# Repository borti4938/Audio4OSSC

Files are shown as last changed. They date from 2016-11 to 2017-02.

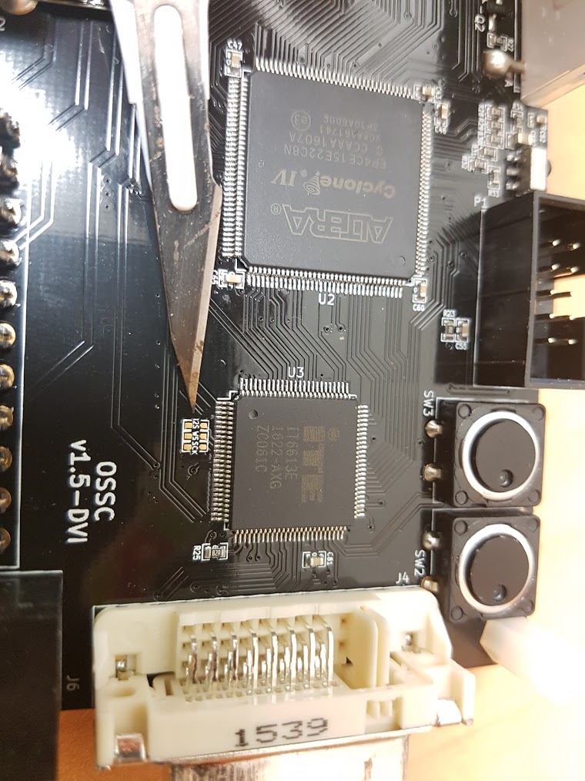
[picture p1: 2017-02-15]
installation/v1.5-A3a/installation_ae_02a.jpg

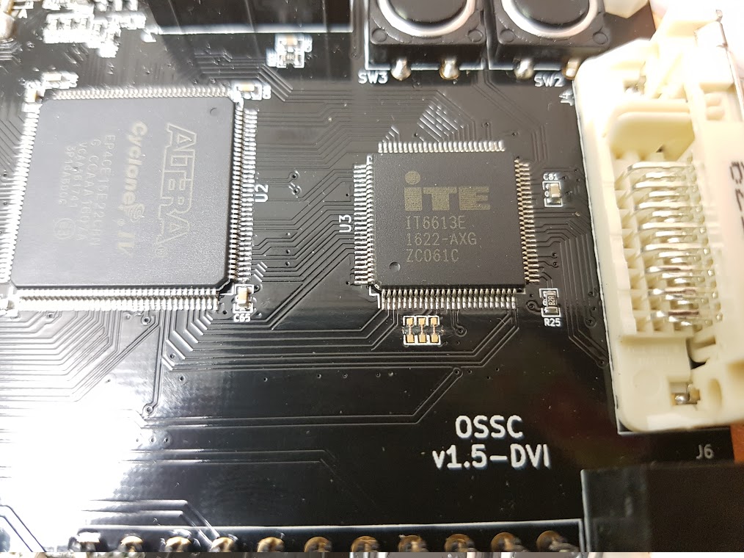
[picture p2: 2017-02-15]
installation/v1.5-A3a/installation_ae_02b.jpg

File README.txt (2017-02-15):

The OSSC does not output audio over HDMI or DVI-D, respectively. This add on captures the analoge audio you feed over the SCART or audio 3.5mm stereo jack. The audio signal is digitalize and put into the IT6613E over the I2S audio interface.
This repository provides the hardware design for the modification. The installation requires installation effort which depends on the OSSC version number you have.

Firmware
========
The IT6613E has to be programmed appropriately to insert audio to the digital video output. In the 'original' firmware audio is not taken into account. Therefore the firmware of the OSSC has to be updated.
Up to the OSSC firmware version v0.73 you can grab the current firmware in this repository. With v0.74 the source code part needed for the audio modification was integrated to the official GitHub branch by marqs85. The builds can be grabbed from the official source: https://www.niksula.hut.fi/~mhiienka/ossc/fw/. Additionally, I provide a mirror here.

PCB Production
==============
Choose the service you would ever like. I have uploaded the design to OSHPark, too.
VERY IMPORTANT: The substrate thickness has to be as thin as possible.
The PCB for v1.3 is design to sit between lifted pins of the IT6613 (the HDMI transmitter) and OSSC-PCB (just look at the installation pictures to get an idea ;)). With v1.5 the OSSC comes with jumpers which are connected to the appropriate pins of the IT6613E. The add-on sits on top of the jumpers (don't forget to open them). 
I have produced the PCBs with OSHPark and have chosen 0.8mm thickness. The PCB must not be thicker.
Link to PCB at OSHPark:
- https://oshpark.com/shared_projects/rmFBAKyo (for v1.3)
- https://oshpark.com/shared_projects/vKUEgBSy (for v1.5)
- https://oshpark.com/shared_projects/WeKdeoGP (for v1.5 with wired connection to the SCART)

Part list of the DIY-Audio PCB
==============================
running number ------ footprint(s) --------- device/part --------- package ----- mouser ordering key
     01         |  U1                 |  PCM1808               |  TSSOP14     |  595-PCM1808PWR
     02         |  U2                 |  74LVC1G34             |  SOT23-5     |  595-SN74LVC1G34DCKR
     03         |  U3                 |  MK2705SLF             |  SOIC8       |  972-MK2705SLF
     04         |  FB1, FB2           |  Ferrit Beat           |  SMD0603     |  81-BLM18PG471SN1D
     05         |  C1                 |  tantal-cap. 47uF/16V  |  SMD case C  |  74-293D476X9016C2TE3
     06         |  R11, R12           |  res. >2.2 kOhm        |  SMD0603     |  71-CRCW06034K99FKEAH (e.g. 4.99k)
     07         |  C11, C13, C15      |  tantal-cap. 10uF/6.3V |  SMD case A  |  74-TR3A106M6R3C1500
     08         |  C12, C14, C16, C21 | cap. 0.1uF/50V         |  SMD0603     |  77-VJ0603V104MXACBC
     09         |  C17, C18, C31      | tantal-cap. 1uF/16V    |  SMD case A  |  74-293D105X9016A2TE3
     10         |  R19, R20           | res. ***               |  SMD0603     |  see description below
     11         |  C19, C20           | cap. ***               |  SMD0603     |  see description below
     12         |  R31                | res. 33 Ohm            |  SMD0603     |  71-CRCW060333R0FKEAH
     13         |  C32, C33           | cap. 0.01uF/50V        |  SMD0603     |  77-VJ0603Y103KXACBC

RC-filtering of the Audio
=========================
The RC filters (R19,C19) and (R20,C20) mainly bandlimits the noise. The filter also avoids aliasing effects if the bandwith of the audio signal increases.
The PCM1808 samples the audio signal with 96kHz. This means that the cut-off frequency of the filters have to be 96kHz or below. The firmware will also allows you to further downsample the datastream to 48kHz. If you want to use that I recommend you to set the filter to 48kHz or below to avoid aliasing.
The cut-off frequency f_c of a simple RC low pass filter is determined by f_c = 1/(2*pi*R*C).
here is my choice which gives a cut-off frequency of 47.938kHz.
     10         |  R19, R20  |  res. 3.32 kOhm   |  SMD0603  |  71-CRCW0603-3.32K-E3  
     11         |  C19, C20  |  cap. 1000pF/50V  |  SMD0603  |  77-VJ0603Y102KXACBC

PCB-Installation
================  
See folder installation ;)
  
For providing pictures, thank you to  
- Kharmeleon (user from Circuit-Board.de)  
- Kabloui (user/customer from VGP)

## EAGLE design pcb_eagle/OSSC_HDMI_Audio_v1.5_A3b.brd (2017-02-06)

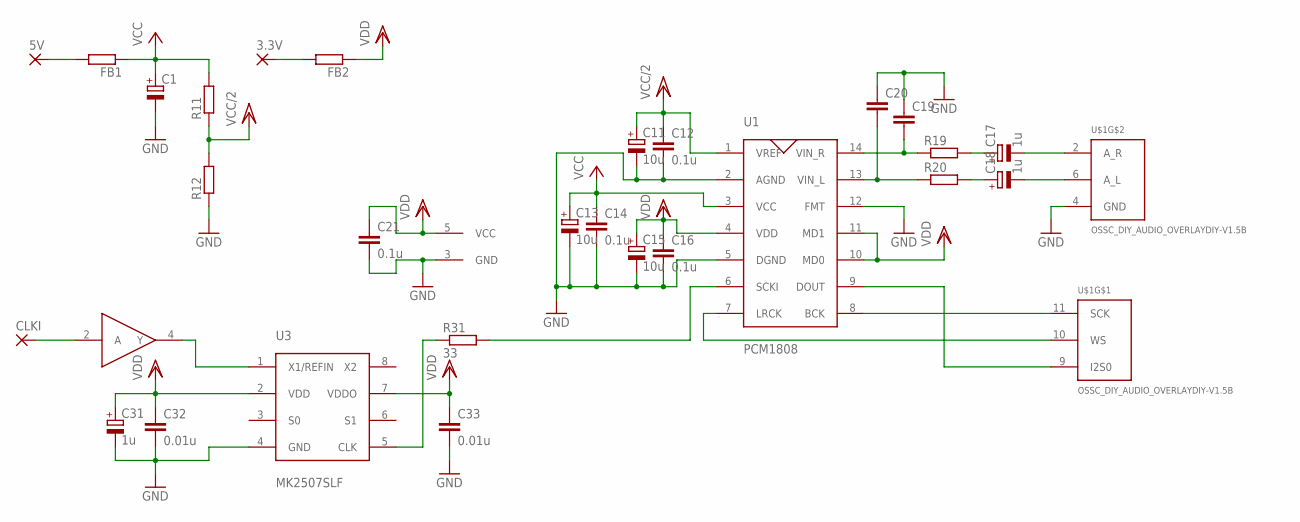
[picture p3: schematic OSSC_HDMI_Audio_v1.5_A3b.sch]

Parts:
3.3V, 5V: SMD2; SMD1,27-2,54
C1: CPOL-EUSMCC; SMC_C
C11, C13, C15: 10u; SMC_A
C12, C14, C16, C21: 0.1u; C0603
C17, C18, C31: 1u; SMC_A
C19, C20: C-EUC0603; C0603
C32, C33: 0.01u; C0603
CLKI: SMD2; SMD1,27-2,54
FB1, FB2: R-EU_R0603; R0603
R11, R12, R19, R20: R-EU_R0603; R0603
R31: 33; R0603
U1: PCM1808
U2: 74LVC1G34; 74LVC1G34DCK
U3: MK2507SLF; SOIC8
U$1: OSSC_DIY_AUDIO_OVERLAYDIY-V1.5B; OSSC_OVERLAY_V1.5B

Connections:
GND: C1.-, C11.-, C12.2, C13.-, C14.2, C15.-, C16.2, C19.1, C20.1, C21.2, C31.-, C32.2, C33.2, R12.1, U1.2 (AGND), U1.5 (DGND), U1.12 (FMT), U2.3 (GND), U3.4 (GND), U$1.4 (GND)
unnamed: C18.-, U$1.6 (A_L)
unnamed: C17.-, U$1.2 (A_R)
unnamed: C17.+, R19.2
unnamed: C19.2, R19.1, U1.14 (VIN_R)
unnamed: C20.2, R20.1, U1.13 (VIN_L)
unnamed: C18.+, R20.2
unnamed: R31.1, U3.5 (CLK)
unnamed: U2.4 (Y), U3.1 (X1/REFIN)
unnamed: CLKI.1, U2.2 (A)
unnamed: 5V.1, FB1.2
unnamed: 3.3V.1, FB2.2
unnamed: U1.7 (LRCK), U$1.10 (WS)
unnamed: U1.8 (BCK), U$1.11 (SCK)
unnamed: U1.9 (DOUT), U$1.9 (I2S0)
unnamed: R31.2, U1.6 (SCKI)
VCC: C1.+, C13.+, C14.1, FB1.1, R11.2, U1.3 (VCC)
VCC/2: C11.+, C12.1, R11.1, R12.2, U1.1 (VREF)
VDD: C15.+, C16.1, C21.1, C31.+, C32.1, C33.1, FB2.1, U1.4 (VDD), U1.10 (MD0), U1.11 (MD1), U2.5 (VCC), U3.2 (VDD), U3.7 (VDDO)

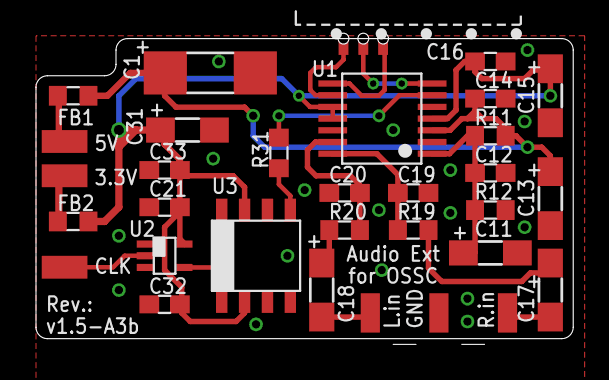
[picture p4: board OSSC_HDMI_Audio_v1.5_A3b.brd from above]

Board: 2 copper layers, 29.8 x 16.7 mm, 29 parts (0 on the bottom side), 19 nets.

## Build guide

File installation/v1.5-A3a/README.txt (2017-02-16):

PCB-Installation on a v1.5-A3a Audio PCB  
========================================  
  
Before you start, check the following points:  
- Your OSSC is pre-assembled?  
  -> If yes, you have to desolder the SCART connector first.  
- Bought a a v1.3-DIY/DVI OSSC?  
  -> If yes, please consider additional notes.  
  
The pictures assumes that you have the SCART connector desoldered from the OSSC board.  
Now you can start :)  
  
01 - cut three wires between each pair of solder joints marked with I2S, WS and SCK  
     -> Note for v1.3: You don't have these jumpers. Lift pins 9, 10 and 11 of the IT6613E.  
02 - demonstration of point 1 on a v1.5-DVI board  
03 - cut off the plastic around pin 2, 4 and 6 of the SCART connector  
04 - solder the SCART plug into place and solder the audio PCB onto the SCART connector (remind to check jumper assignment at next to the IT6613E during soldering the first leg)  
05 - solder the three top solder joints on the OSSC PCB (I2S, WS and SCK) to the audio PCB  
     -> make sure that you don't reconnect the jumpers to GND with your solder  
     -> Note for v1.3: Solder lose wires to the lifted pins. Be carefull to not harm the pins!  
06 - connect the wires for 5V, 3.3V and 27MHz  
07 - 5V and 3.3V can be get from U5  
08 - 27MHz from the crystal oscillator (pin between U7 and U9)

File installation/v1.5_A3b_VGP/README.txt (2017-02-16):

PCB-Installation on a v1.5-A3b Audio PCB
========================================
(This is the version you can buy from VGP)  

Before you start, check the following points:  
- Bought a a v1.3-DIY/DVI OSSC?  
  -> If yes, please consider additional notes.  
  
Now you can start :)  
  
01 - cut three wires between each pair of solder joints marked with I2S, WS and SCK
     -> Note for v1.3: You don't have these jumpers. Lift pins 9, 10 and 11 of the IT6613E.  
02 - demonstration of point 1 on a v1.5-DVI board  
03 - solder the three top solder joints on the OSSC PCB (I2S, WS and SCK) to the audio PCB  
     -> Note for v1.3: Solder lose wires to the lifted pins. Be carefull to not harm the pins!   
   - solder three wires to the SCART plug w (L.in <-> pin 6, GND <-> pin 4, R.in <-> pin 2)
04 - connect the wires for 5V, 3.3V and 27MHz  
05 - 5V and 3.3V can be get from U5
06 - 27MHz from the crystal oscillator (pin between U7 and U9)

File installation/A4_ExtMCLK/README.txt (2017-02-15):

External MCLK (read update, too)
================================
  
Update:
marqs has found out that the problem was related to a bug of the IT6613E. Setting the output audio mode flag to standard I2S forced the IT6613E to use 16bit word length instead of 24bit as it is. Setting this flag to use '32bit' fixed that and the IT6613E uses 24bit then. See this commit and especially this line here: https://github.com/marqs85/ossc/commit/fac88b348e32807aa04aa2773f0e064f15f79182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
Please report if you observe problems despite that change? Does it makes any difference between using internally generated MCLK or externally provided MCLK?  

old text:  
The IT6613E derives the system clock for audio processing (audio master clock, MCLK) from the I2S input (I2S0, WS and SCK) by default. It is also possible to feed the MCLK into the IT6613E using pin 5 and setting appropriate register bits.
If you have problems with the internally derived MCLK of the IT6613E, you have to use the external MCLK. Problems mean that you might have audio dropouts or you simply hear nothing! Then you have to use the external MCLK.
  
Firmware  
========  
Due to the latest update, the external master clock is not supported by official firmware. A simple hardware modification does not change anything. However, this repository provides firmware build to use the external clock. ONLY use that firmware along with the hardware modification described here.  
The firmware has the ext. mclk enabled! This cannot be changed in the menu.  
  
Hardware Modification
=====================
  
Next to using the inofficial firmware you have to modify your OSSC a bit.
- older audio boards v1.5-A3x, v1.3-A3, and before: lift pin 5 of the IT6613E and connect the pin with R31 (top pad; see picture 10) 
- newer audio boards v1.3-A4: designed to lift pin 5 before installation. Nothing more to done.
- newer audio boards v1.5-A4x: lift pin 5 and connect the pin with the pad 'MCLK' on the audio add-on board

Pictures  
========  
  
10 - Pin 5 of the IT6613E lifted and connected to R31 (top pad) (only if you want to use the external MCLK)

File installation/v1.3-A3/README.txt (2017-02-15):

PCB-Installation of a v1.3-A3 Audio PCB  
=======================================  
  
Before you start, check the following points:  
- Your v1.3-DVI/DIY OSSC is pre-assembled?  
  -> If yes, you have to desolder the SCART connector first and lift pins 9, 10 and 11 of the IT6613E IC.  
- Have a v1.5-DVI/DIY OSSC and the v1.3-A3 add on board?  
  -> If yes, stay here.  
- Bought a a v1.5-DIY/DVI OSSC?  
  -> If yes, you are in the wrong folder.  
  
The pictures assumes that you have spare IT6613E, OSSC board and SCART connector. Now you can start :)  
  
01 - bend up pins 9, 10 and 11 of the IT6613 (v1.3 only!!!) (and eventually pin 5 - see External MCLK; not supported by official firmware)  
02 - make a placement check  
03 - cut off the plastic around pin 2, 4 and 6 of the SCART connector (not needed if you have the version with wired connection to the SCART, e.g. if you bought your board from VGP)  
04 - solder the IT6613 into place (if not done yet) and approximately fix the audio pcb into place  
05 - solder the SCART plug into place and solder the audio PCB onto the SCART connector (remind to check the pin assignment at the IT6613 during soldering the first leg)  
06 - solder pin 9, 10 and 11 of the IT6613 onto the audio PCB  
07 - connect the wires for 5V, 3.3V and 27MHz  
08 - 5V and 3.3V can be get from U5  
09 - 27MHz from the crystal oscillator (pin between U7 and U9)

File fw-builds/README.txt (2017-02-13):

v0.73 and before: just a backup, here

v0.74 and later: The audio firmware was included to the official GitHub repository of marqs85. These firmware files are just a mirror from the official source: https://www.niksula.hut.fi/~mhiienka/ossc/fw/

fw-build with extension "-wextmclk": IT6613E uses the external audio clock. Uses this fw. only if you want to use it (see notes on the main-readme)

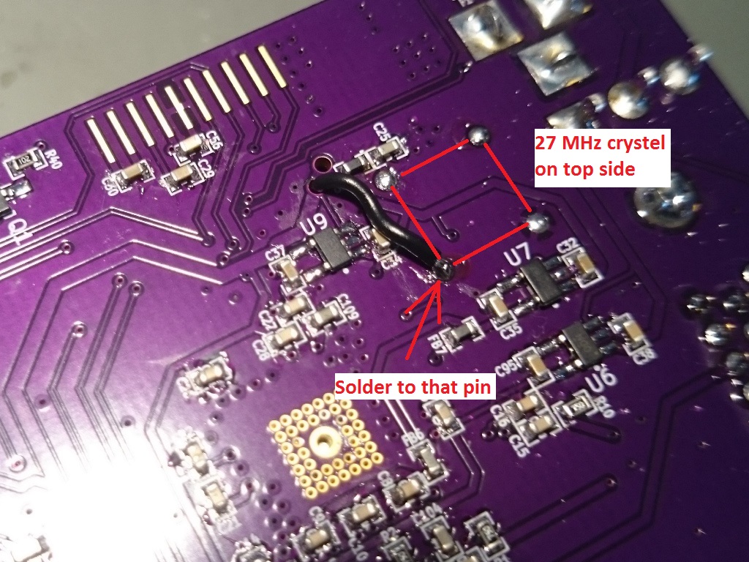
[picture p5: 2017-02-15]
installation/v1.5-A3a/installation_ae_08.JPG

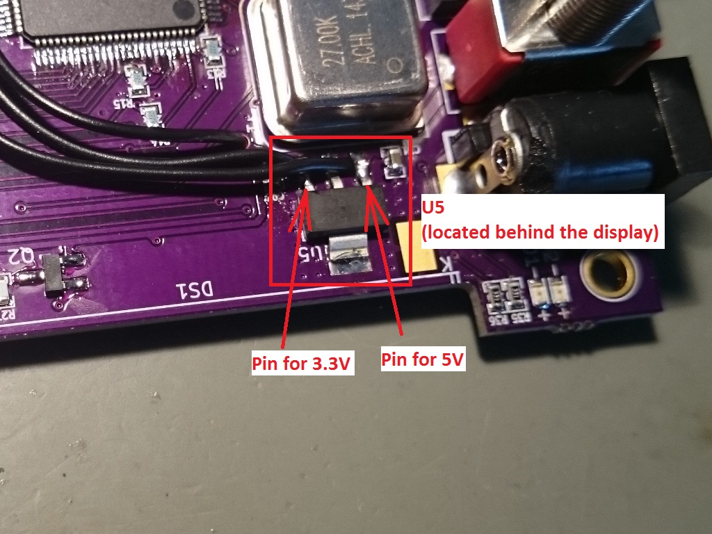
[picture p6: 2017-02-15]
installation/v1.3-A3/installation_ae_08.JPG

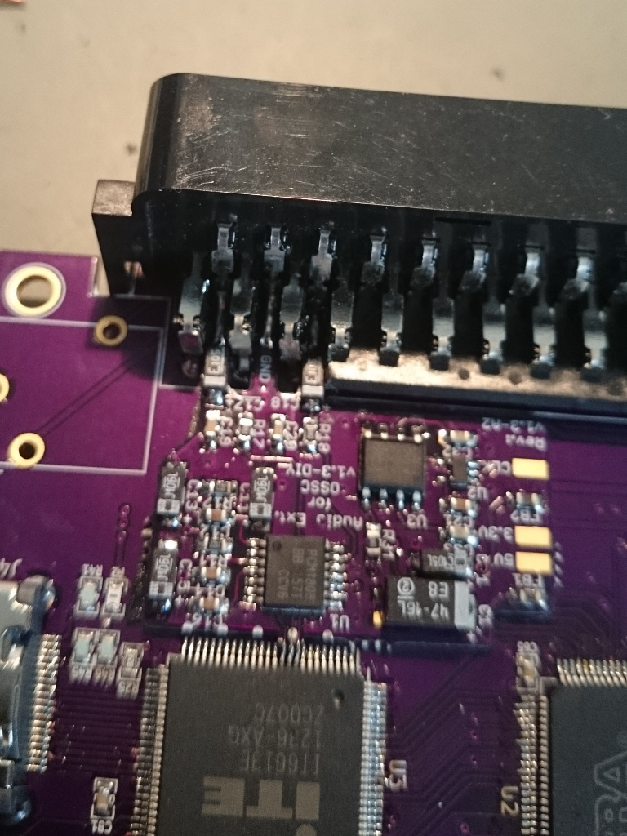
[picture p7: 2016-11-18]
installation/v1.3-A3/installation_ae_06.JPG

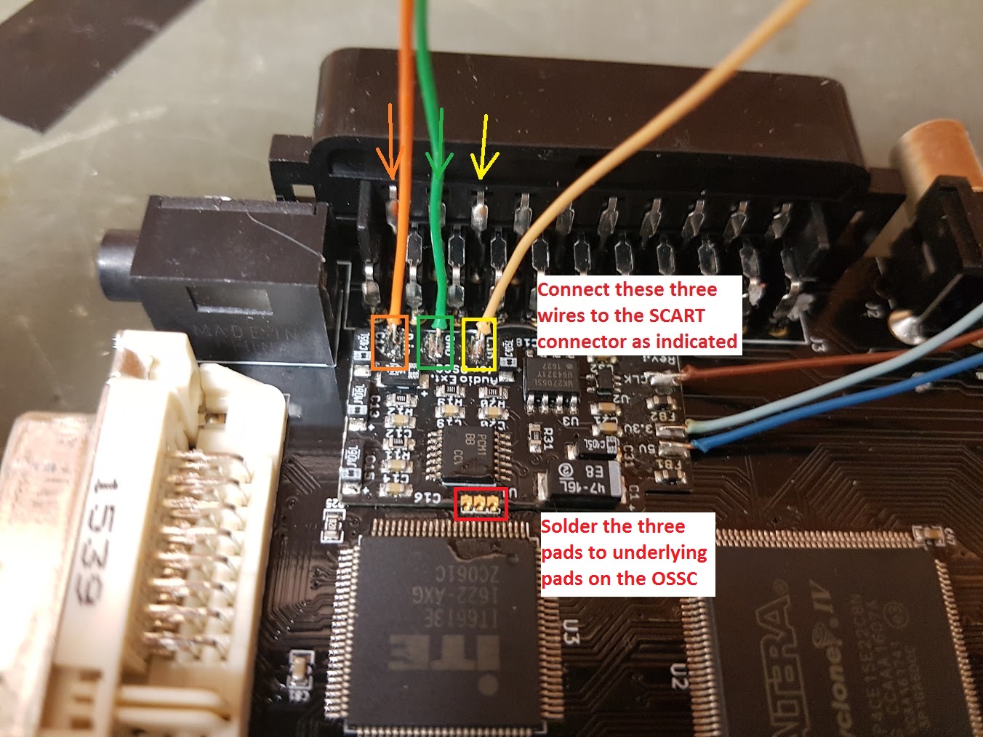
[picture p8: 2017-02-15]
installation/v1.5_A3b_VGP/installation_ae_03.jpg

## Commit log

2017-01-09 External Masterclock option removed in OSSC firmware v0.75 - PCB files back to A3 - backed up A4 in additional sub-folder
    [OSSC_HDMI_Audio_v1.3_A3.brd, OSSC_HDMI_Audio_v1.3_A3.sch, OSSC_HDMI_Audio_v1.3_A4.brd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]
2017-02-06 Fix: remove needless wire and silkscreen from PCB
    [OSSC_HDMI_Audio_v1.5_A3b.brd]
2017-02-15 Update PCB installation
2017-06-16 Update fw-files: although I don’t understand the reason, building the firmware with Quarts Prime Lite 15.1 caused issues (interferences on screen) which are mostly visible in LineX5 mode. Now the fw 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
